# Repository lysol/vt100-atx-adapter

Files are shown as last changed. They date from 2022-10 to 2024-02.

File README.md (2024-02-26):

Warning: This part worked for me, but there may be variations in DEC VT100 terminals or
terminals based on the VT100 (like the VT105, which I have). I've attempted to accomodate
what differences I may have encountered in research but definitely consult your model's
documentation to ensure its compatibility before building one blindly
and frying your terminal.

VT100 ATX Adapter
-----------------

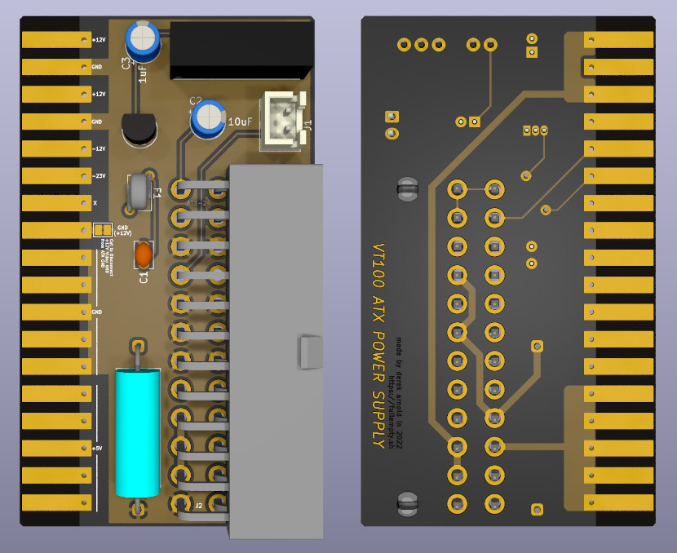
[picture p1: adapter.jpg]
Board Render


Like others with DEC VT10X terminals, the power supply board in mine
wasn't working. I've started off with bbenchoff's [here](https://github.com/bbenchoff/VT100Adapter),
but had to modify it to make it work with my VT105, which is essentially
a stock VT100 with Advanced Video and Waveform Graphics boards.

This version corrects the 12V/GND pin placement on the edge
connector (12V GND 12V GND, rather than 12V GND GND GND),
and uses an isolated DC-DC converter to generate -23 (well, -24) volts.
The VT100 Basic Video board uses the potential between +12V
and the -23V to generate the -35V supply for the ER1400
NVRAM. This is mostly possible because of the extremely low (10mA)
current maximum of the original -23V line, and the +/- 8%
tolerance of the -35V requirement for said IC.

I've also corrected the edge trace pitch, as bbenchoff's,
while still functional, is slightly off and some of the pins
are close to the edge of the traces.

* [Bill of Materials](VT100_ATX_DCDC.csv)
* [Schematic](VT100_ATX_DCDC.pdf)

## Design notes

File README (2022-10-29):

VT100 ATX Adapter
-----------------

Like others with DEC VT10X terminals, the power supply board in mine
wasn't working. I've started off with bbenchoff's here:

https://github.com/bbenchoff/VT100Adapter

But the pinout is just flat wrong, at least for my VT105, and
according to the technical documentation for the VT100,
which is widely available on Bitsavers.

This version corrects the 12V/GND pin placement on the edge
connector (12V GND 12V GND, rather than 12V GND GND GND),
and uses a soon-to-be obsolete DC-DC converter
for converting +5V to negative voltages, specifically -24V,
which is in tolerance for the NVRAM for the VT10X terminals,
which is absolutely required for the self-check to even complete
on startup.

I've also corrected the edge trace pitch, as bbenchoff's,
while still functional, is slightly off and some of the pins
are close to the edge of the traces.

You could still use this board with a linear supply setup
if you can't source the NMT0572SC; you'll need to supply
your own step-down transformer and rectifier, but those
sorts of circuits are extremely simple and widely available
on the internet, and bbenchoff's adapter is a good reference
for such a design. The current draw of a VT100's -23V rail
is specified as 10mA, so you have a lot of rectifiers that
would work, not necessarily the one in the BOM for the other
adapter.

For now the NMT0572SC seems to be widely available, and a
convenient option.

For silly reasons I have a large rectangle on both F.MASK
and B.MASK, making it a solder mask-less board. Delete them
in KiCAD if you'd like a reasonable looking solder mask,
as I designed it with a normal solder mask to begin with.

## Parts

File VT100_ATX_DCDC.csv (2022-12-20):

Reference | Value | Footprint | Datasheet | Digi-Key Part Number | Manufacturer | Part Number
C1 | C_Small | Capacitor_THT:C_Disc_D3.8mm_W2.6mm_P2.50mm | https://connect.kemet.com:7667/gateway/IntelliData-ComponentDocumentation/1.0/download/datasheet/C315C104M5U5TA | 399-4151-ND | Kemet | C315C104M5U5TA
C2 | 10uF | Capacitor_THT:CP_Radial_D5.0mm_P2.00mm | https://www.we-online.com/katalog/datasheet/860010372001.pdf | 732-8593-1-ND | Würth Elektronik | 860010372001
C3 | 1uF | Capacitor_THT:CP_Radial_D5.0mm_P2.00mm | https://www.we-online.com/katalog/datasheet/860020672005.pdf | 732-8851-1-ND | Würth Elektronik | 860020672005
F1 | Polyfuse | VT105_Library:CMF-RL25U-0 | https://www.bourns.com/docs/Product-Datasheets/cmfrl.pdf | CMF-RL25U-0-ND | Bourns Inc. | CMF-RL25U-0
J1 | Power Switch | Connector_JST:JST_XH_B2B-XH-A_1x02_P2.50mm_Vertical |  | 455-2247-ND | JST Sales America Inc. | B2B-XH-A(LF)(SN)
J2 | ATX-24 | Connectors:ATX24_RIGHT_ANGLE | https://www.molex.com/pdm_docs/sd/039301240_sd.pdf | WM1362-ND | Molex | 0039301240
R1 | RES 6.8 OHM 5% 5W AXIAL | VT105_Library:ROX5SSJ6R8 |  | A142748CT-ND | TE Connectivity Passive Product | ROX5SSJ6R8
U1 | A0324S-1WR3 DC-DC Converter | VT105_Library:A0324S-1WR3‎ | https://www.mornsun-power.com/html/pdf/A0324S-1WR3.html | 2725-A0324S-1WR3-ND | Mornsun America, LLC | A0324S-1WR3
U3 | MC79L24 -24V Voltage Regulator | Package_TO_SOT_THT:TO-92_Inline | https://www.onsemi.com/pdf/datasheet/mc79l00-d.pdf | MC79L24ABPG-ND | onsemi | MC79L24ABPG

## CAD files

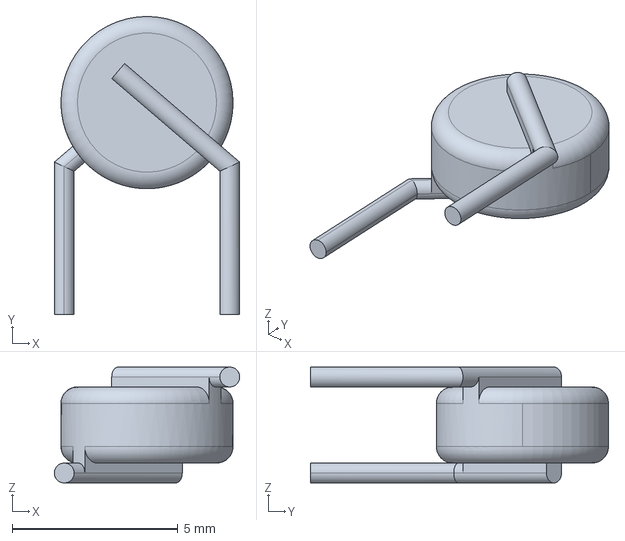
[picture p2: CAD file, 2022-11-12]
3dmodels/cmf-rl25u.stp
5.60 x 9.00 x 3.50 mm

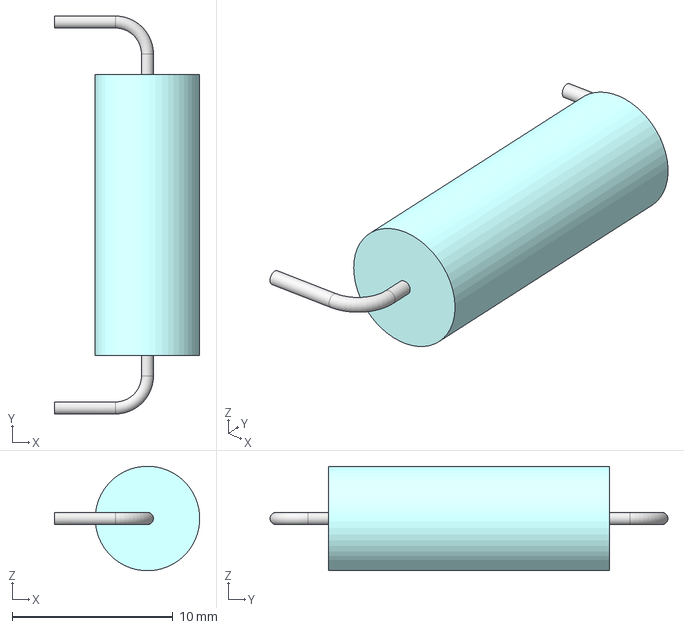
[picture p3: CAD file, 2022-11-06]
3dmodels/ROX5SSJ6R8.step
9.03 x 24.8 x 6.50 mm

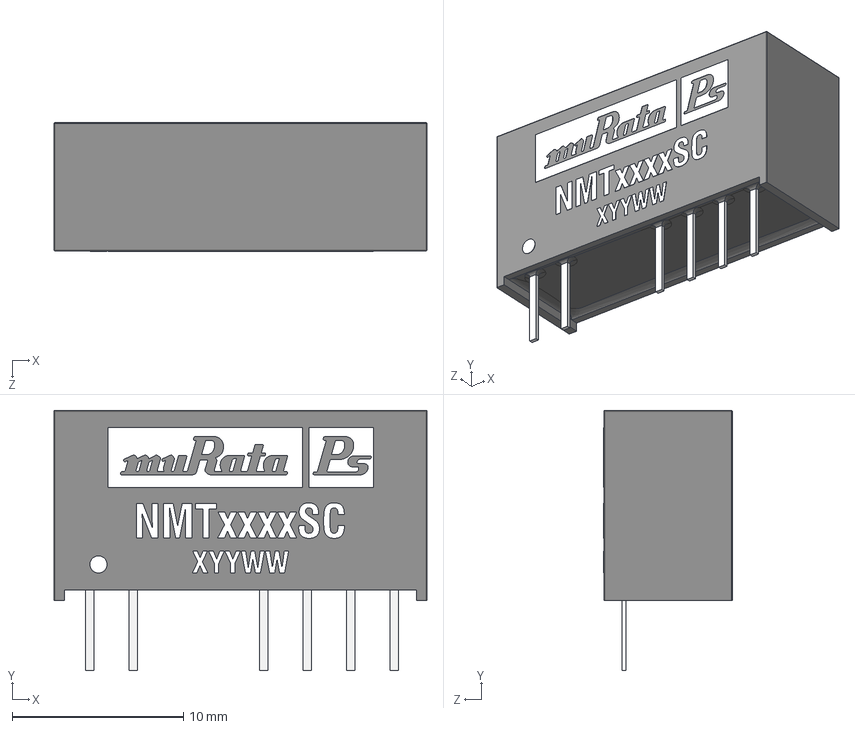
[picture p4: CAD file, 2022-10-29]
3dmodels/mps_dcdc_nmt_sc_a.step
21.8 x 15.2 x 7.52 mm

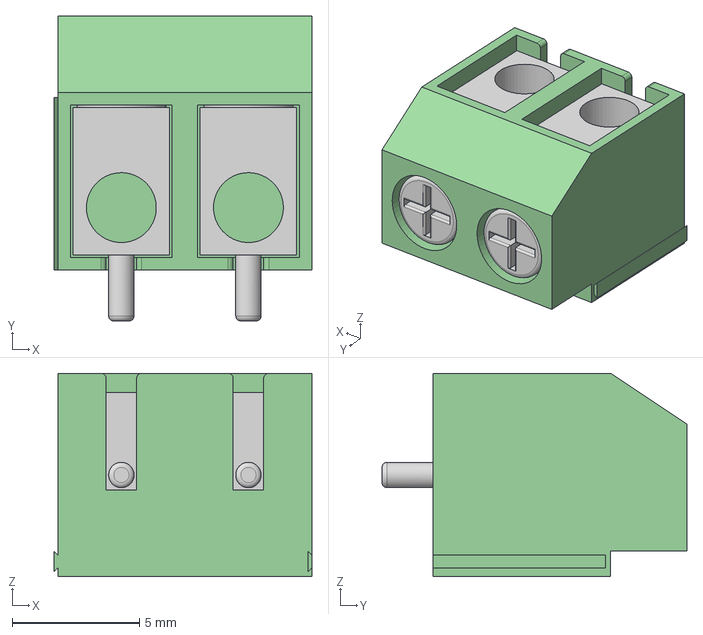
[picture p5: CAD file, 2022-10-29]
3dmodels/Screw Terminal Block 5mm 2-way.step
10.2 x 12.0 x 8.00 mm

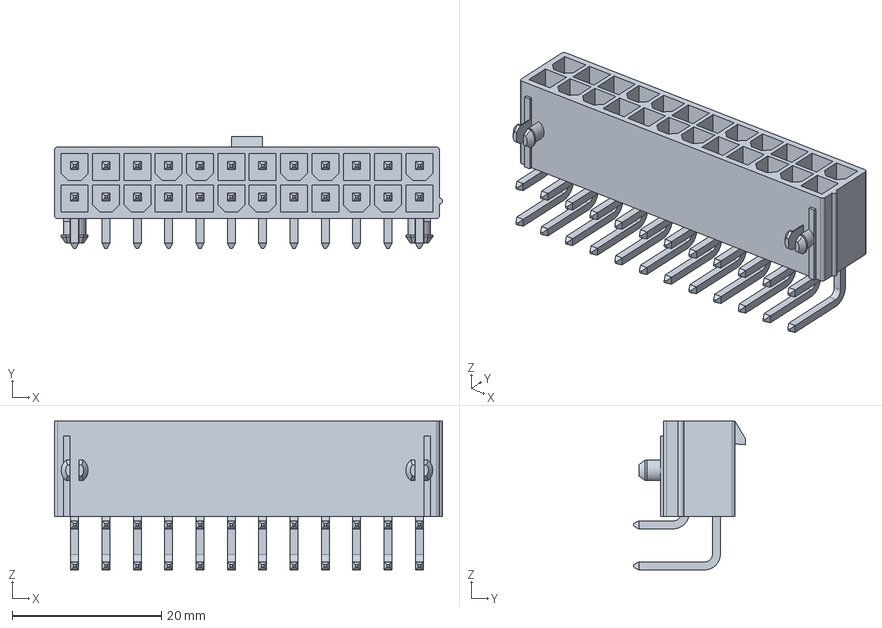
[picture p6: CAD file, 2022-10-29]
3dmodels/039301240.stp
52.0 x 15.0 x 19.9 mm

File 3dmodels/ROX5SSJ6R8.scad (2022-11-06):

$fn=32;

length=17.5;
diameter=6.5;
lead_diameter=0.75;
lead_length=3.5;
lead_spacing=24;
curve_distance=2;
lead_below_resistor = 2.54;

module bent_lead() {
  rotate_extrude(angle=90) translate([curve_distance, 0, 0]) circle(d=lead_diameter);
}

rotate([-90, 0, 180]) {
  color("#AAFFFF") cylinder(d=diameter, h=length, center=true);
  color("silver") {
    cylinder(d=lead_diameter, h=lead_spacing - curve_distance * 2, center=true);
    translate([curve_distance, 0, lead_spacing / 2 - curve_distance])
      rotate([0, -90, 90]) bent_lead();
    translate([curve_distance, 0, -lead_spacing / 2 + curve_distance])
      rotate([0, 90, 90]) bent_lead();
    translate([lead_below_resistor + curve_distance / 2 + lead_diameter / 2 - 0.02, 0, -lead_spacing / 2])
      rotate([0, 90, 0])
        cylinder(h=diameter / 2 + lead_below_resistor - curve_distance, d=lead_diameter, center=true);
    translate([lead_below_resistor + curve_distance / 2 + lead_diameter / 2 - 0.02, 0, lead_spacing / 2])
      rotate([0, 90, 0])
        cylinder(h=diameter / 2 + lead_below_resistor - curve_distance, d=lead_diameter, center=true);
  }
}

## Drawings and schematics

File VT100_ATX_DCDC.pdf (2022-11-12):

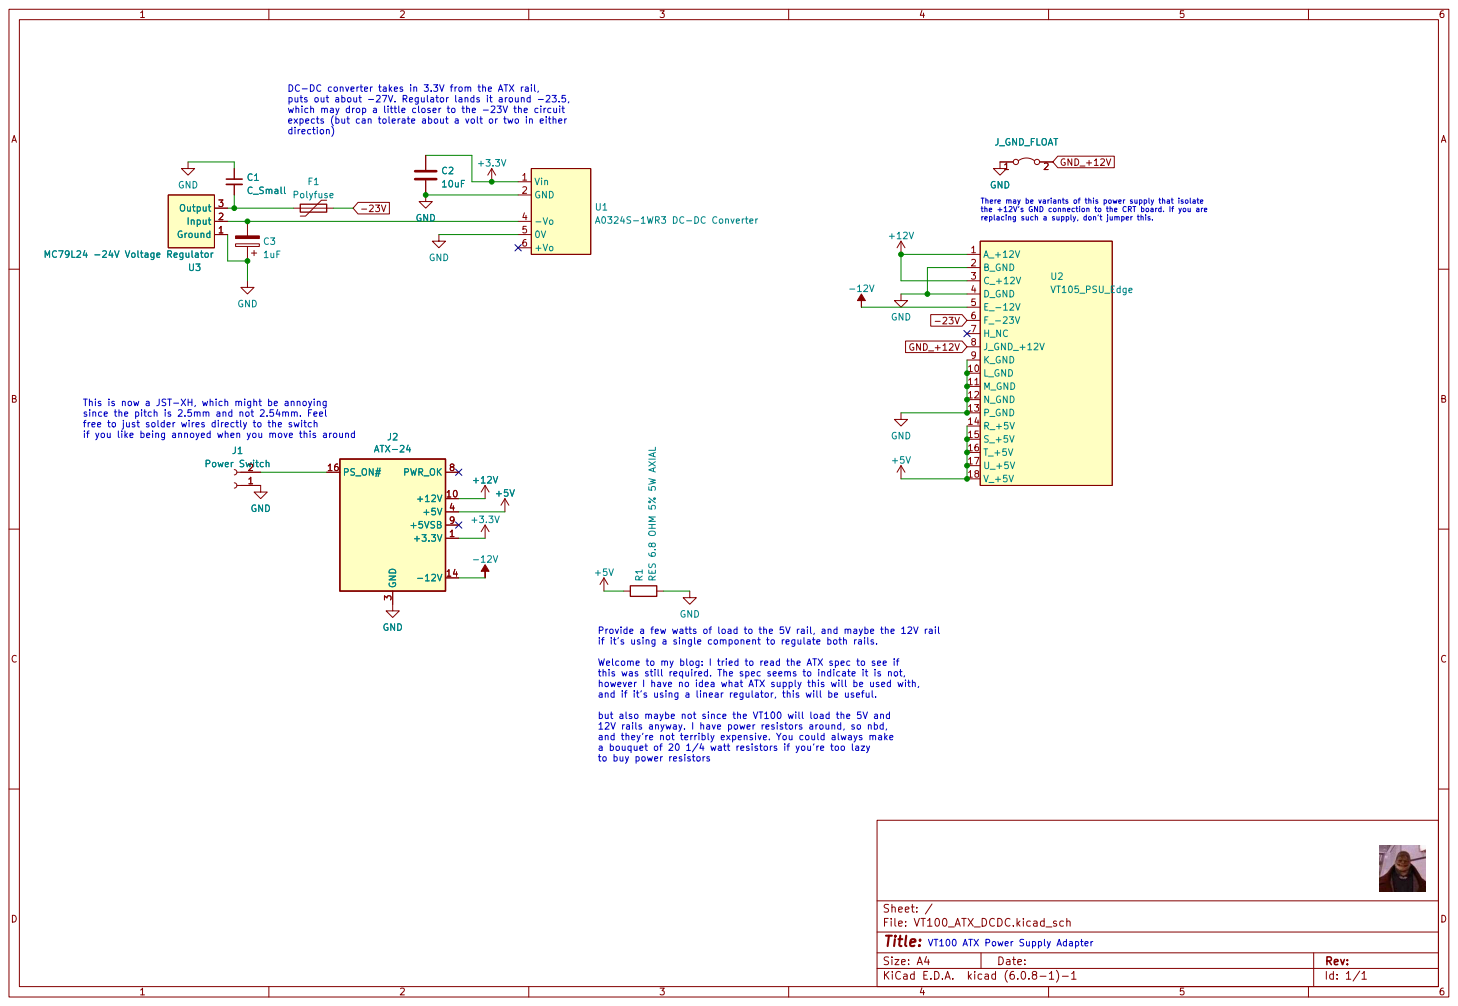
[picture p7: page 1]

DC-DC converter takes in 3.3V from the ATX rail, puts out about -27V. Regulator lands it around -23.5,
C1C_Small J1 Power Switch
J1 Power Switch GND

which may drop a little closer to the -23V the circuit
expects (but can tolerate about a volt or two in either

the +12V's GND connection to the CRT board. If you are
replacing such a supply, don't jumper this.

This is now a JST-XH, which might be annoying
since the pitch is 2.5mm and not 2.54mm. Feel
free to just solder wires directly to the switch
if you like being annoyed when you move this around

Provide a few watts of load to the 5V rail, and maybe the 12V rail
if it's using a single component to regulate both rails.

Welcome to my blog: I tried to read the ATX spec to see if
this was still required. The spec seems to indicate it is not,
however I have no idea what ATX supply this will be used with,
and if it's using a linear regulator, this will be useful.

but also maybe not since the VT100 will load the 5V and
12V rails anyway. I have power resistors around, so nbd,
and they're not terribly expensive. You could always make
a bouquet of 20 1/4 watt resistors if you're too lazy
to buy power resistors

VT100 ATX Power Supply Adapter

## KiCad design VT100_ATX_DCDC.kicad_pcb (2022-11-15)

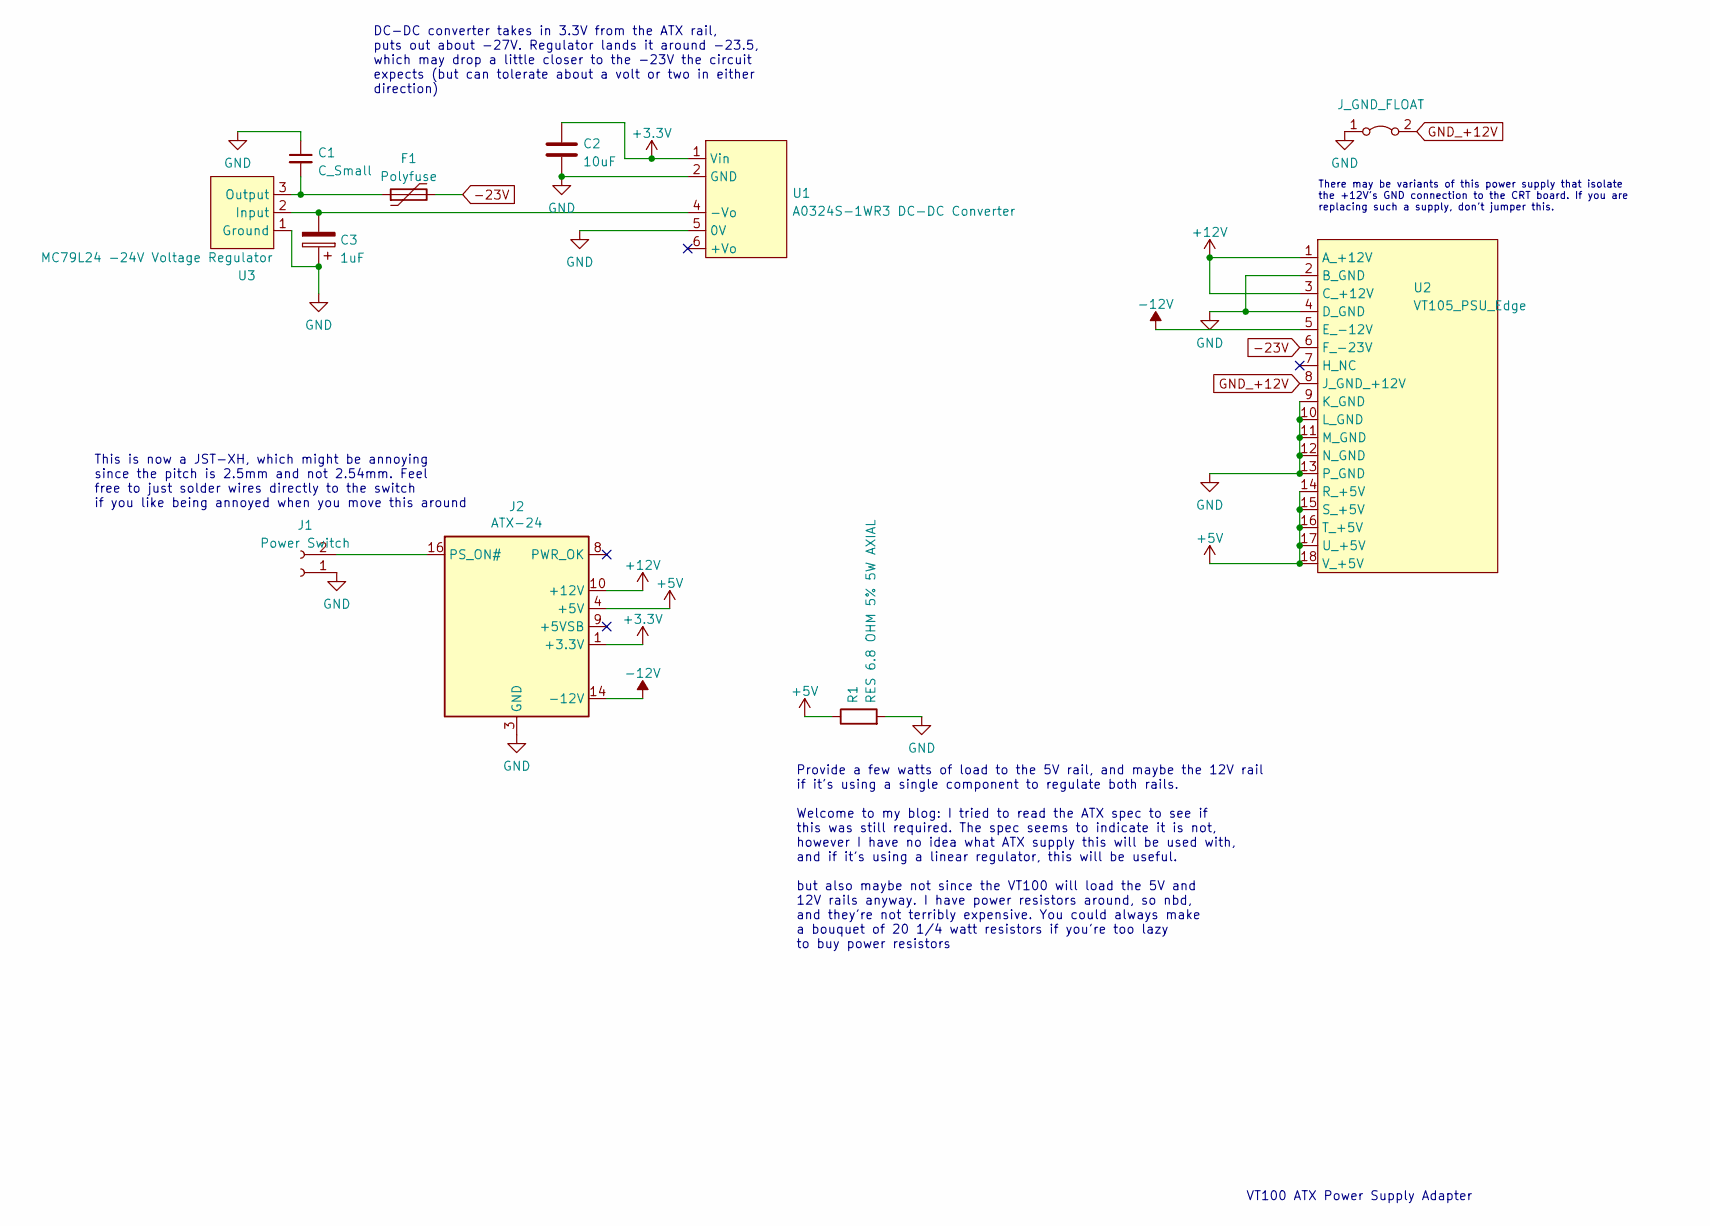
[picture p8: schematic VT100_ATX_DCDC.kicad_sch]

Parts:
C1: C_Small; C_Disc_D3.8mm_W2.6mm_P2.50mm; Part Number C315C104M5U5TA; Digi-Key Part Number 399-4151-ND
C2: 10uF; CP_Radial_D5.0mm_P2.00mm; Part Number 860010372001; Digi-Key Part Number 732-8593-1-ND
C3: 1uF; CP_Radial_D5.0mm_P2.00mm; Part Number 860020672005; Digi-Key Part Number 732-8851-1-ND
F1: Polyfuse; CMF-RL25U-0; Part Number CMF-RL25U-0; Digi-Key Part Number CMF-RL25U-0-ND
J1: Power Switch; JST_XH_B2B-XH-A_1x02_P2.50mm_Vertical; Part Number B2B-XH-A(LF)(SN); Digi-Key Part Number 455-2247-ND
J2: ATX-24; ATX24_RIGHT_ANGLE; Part Number 0039301240; Digi-Key Part Number WM1362-ND
JP1: J_GND_FLOAT; SolderJumper-2_P1.3mm_Bridged2Bar_Pad1.0x1.5mm
R1: RES 6.8 OHM 5% 5W AXIAL; ROX5SSJ6R8; Part Number ROX5SSJ6R8; Digi-Key Part Number A142748CT-ND
U1: A0324S-1WR3 DC-DC Converter; A0324S-1WR3‎; Part Number A0324S-1WR3; Digi-Key Part Number 2725-A0324S-1WR3-ND
U2: VT105_PSU_Edge; VT105_Card_Edge
U3: MC79L24 -24V Voltage Regulator; TO-92_Inline; Part Number MC79L24ABPG; Digi-Key Part Number MC79L24ABPG-ND

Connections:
+3.3V: C2.1, J2.1 (+3.3V), J2.2 (+3.3V), J2.12 (+3.3V), J2.13 (+3.3V), U1.1 (Vin)
+5V: J2.4 (+5V), J2.6 (+5V), J2.21 (+5V), J2.22 (+5V), J2.23 (+5V), R1.1, U2.14 (R_+5V), U2.15 (S_+5V), U2.16 (T_+5V), U2.17 (U_+5V), U2.18 (V_+5V)
+12V: J2.10 (+12V), J2.11 (+12V), U2.1 (A_+12V), U2.3 (C_+12V)
-12V: J2.14 (-12V), U2.5 (E_-12V)
-23V: F1.2, U2.6 (F_-23V)
GND: C1.1, C2.2, C3.1, J1.1, J2.3 (GND), J2.5 (GND), J2.7 (GND), J2.15 (GND), J2.17 (GND), J2.18 (GND), J2.19 (GND), J2.24 (GND), JP1.1 (A), R1.2, U1.2 (GND), U1.5 (0V), U2.2 (B_GND), U2.4 (D_GND), U2.9 (K_GND), U2.10 (L_GND), U2.11 (M_GND), U2.12 (N_GND), U2.13 (P_GND), U3.1 (Ground)
GND_+12V: JP1.2 (B), U2.8 (J_GND_+12V)
unnamed: C1.2, F1.1, U3.3 (Output)
unnamed: C3.2, U1.4 (-Vo), U3.2 (Input)
unnamed: J1.2, J2.16 (PS_ON#)

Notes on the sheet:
VT100 ATX Power Supply Adapter
This is now a JST-XH, which might be annoying since the pitch is 2.5mm and not 2.54mm. Feel free to just solder wires directly to the switch if you like being annoyed when you move this around
Provide a few watts of load to the 5V rail, and maybe the 12V rail if it's using a single component to regulate both rails. Welcome to my blog: I tried to read the ATX spec to see if this was still required. The spec seems to indicate it is not, however I have no idea what ATX supply this will be u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
There may be variants of this power supply that isolate the +12V's GND connection to the CRT board. If you are replacing such a supply, don't jumper this.
DC-DC converter takes in 3.3V from the ATX rail, puts out about -27V. Regulator lands it around -23.5, which may drop a little closer to the -23V the circuit expects (but can tolerate about a volt or two in either direction)

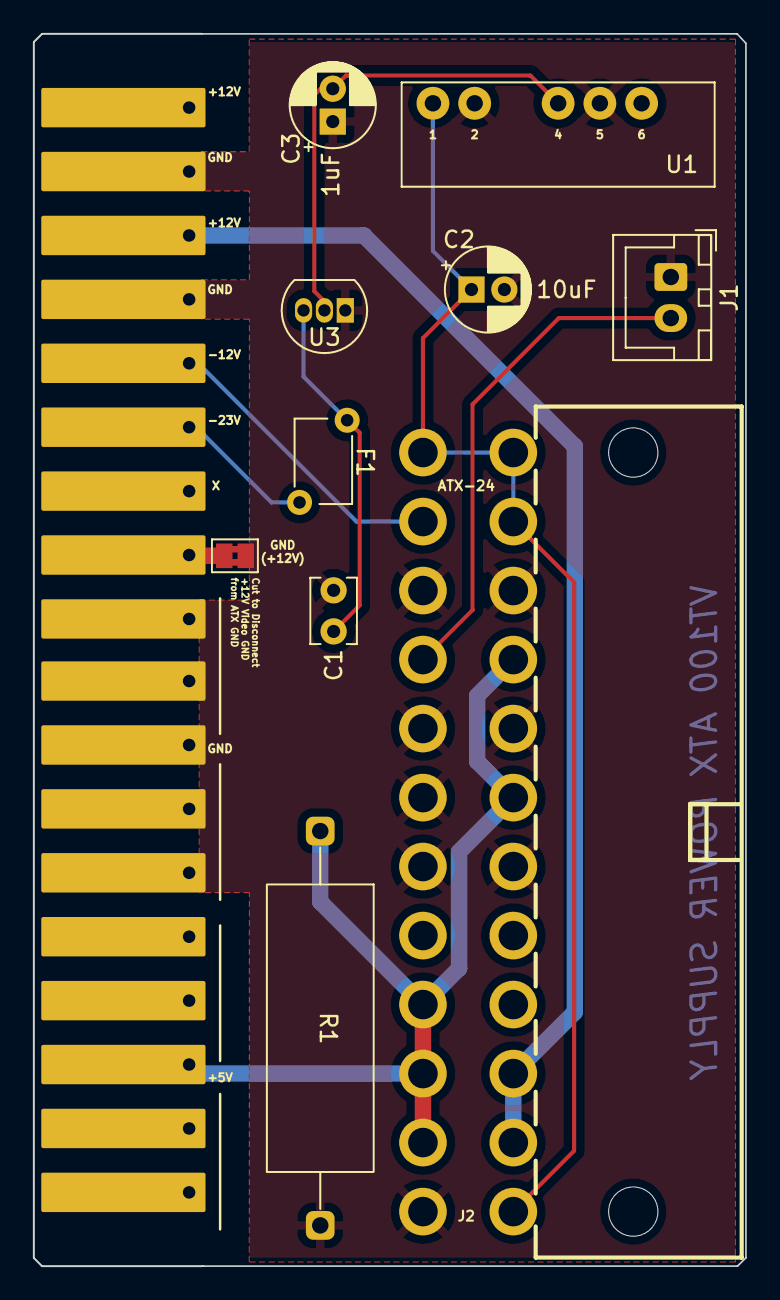
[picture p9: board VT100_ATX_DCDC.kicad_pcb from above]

Board: 2 copper layers, 43.3 x 75.0 mm, 11 parts (0 on the bottom side), 10 nets.

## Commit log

2022-10-29 made the entire board smaller, moved things around
    replaced the cap footprint with a smaller one, since
    you can get small-ish 1uf 50V caps this size easily
    made the power resistor vertical, it looks cool
    and saves space, which the VT100 has plenty of inside
    moved the 12V ground slice location to the back, why not
    grouped various things to make it easier to work on
    new gerbers for it
    removing the bit about no solder mask
    [039301240.stp, Screw Terminal Block 5mm 2-way.step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]
2022-10-29 add BOM
    [VT100_ATX_DCDC.csv]
2022-10-31 add bom fields
    [VT100_ATX_DCDC-B_Cu.gbr, VT100_ATX_DCDC-B_Mask.gbr, VT100_ATX_DCDC-B_Silkscreen.gbr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]
2022-10-31 replace DCDC converter with 555 negative supply circuit
    [VT100_ATX_DCDC-B_Cu.gbr, VT100_ATX_DCDC-B_Mask.gbr, VT100_ATX_DCDC-B_Silkscreen.gbr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]
2022-11-02 use a different power module instead of my jank ass 555 circuit
    [A05_S-1WR3.stp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]
2022-11-05 add voltage regulator for DC-DC converter
    the DC-DC converter came out to like -26.7V, that is too hot man
    [VT100_ATX_DCDC-B_Cu.gbr, VT100_ATX_DCDC-B_Mask.gbr, VT100_ATX_DCDC-B_Silkscreen.gbr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]
2022-11-06 make board a little roomier again, use different resistor
    I made a model for the new one in openscad because the mfg provided
    a model without bent leads for placement in a footprint. why
    would you think that is useful?
    I made it in openscad ok. converted to step using FreeCAD
    [ROX5SSJ6R8.scad, ROX5SSJ6R8.step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]
2022-11-06 add schematic notes, export pdf
    [VT100_ATX_DCDC.kicad_sch]
2022-11-06 add schematic link to readme
2022-11-10 update schematic after testing on the breadboard
    [VT100_ATX_DCDC.kicad_sch]
2022-11-10 eliminate a via
    [VT100_ATX_DCDC-B_Cu.gbr, VT100_ATX_DCDC-B_Mask.gbr, VT100_ATX_DCDC-B_Silkscreen.gbr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]
2022-11-12 add polyfuse, add missing footprint
    [VT100_ATX_DCDC-B_Cu.gbr, VT100_ATX_DCDC-B_Mask.gbr, VT100_ATX_DCDC-B_Silkscreen.gbr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]
2022-11-15 adjust pitch of edge connector to match real edge socket
    [VT100_ATX_DCDC-B_Cu.gbr, VT100_ATX_DCDC-B_Mask.gbr, VT100_ATX_DCDC-B_Silkscreen.gbr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]
2022-12-20 remove jumper, not actually populated
    [VT100_ATX_DCDC.csv]
